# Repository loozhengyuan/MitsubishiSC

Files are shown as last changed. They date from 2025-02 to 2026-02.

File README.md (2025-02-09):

# MitsubishiSC



Smart controller for Mitsubishi Electric HVAC systems.

## Usage

The [`platformio.ini`](./platformio.ini) defines the list of build environments. Each board configuration comes in `debug` and `release` builds.

### Build

To compile the firmware, use the `pio run` command with the designated build environment.

```shell
pio run --environment mitsubishisc_v1_release
```

### Flash

To flash the build artifact to the board, connect the board and run the `pio run` command with the `upload` target.

```shell
pio run --target upload --environment mitsubishisc_v1_release
```

## Concepts

### Protocol

The CN105 connector exposes the UART interface via the RX and TX pins. As [discovered by Hadley Rich](https://nicegear.nz/blog/hacking-a-mitsubishi-heat-pump-air-conditioner/), this uses 5V TTL 2400 8-E-1.

Since the ESP32/STM32 runs on 3.3V while the UART runs on 5V, there is a need to use a logic level shifter. [BSS138](https://www.onsemi.com/pdf/datasheet/bss138-d.pdf) is a N-channel MOSFET with a low $V_{GS(th)}$, which makes it [more ideal than other NMOS components](https://electronics.stackexchange.com/questions/242424/what-can-i-replace-a-bss138-n-channel-mosfet-with).

For more information about the packets, refer to [mUART Protocol Reference](https://muart-group.github.io/developer/packet-reference).

## Hardware

### MCU

As part of the project goals, we want to build a device that leverages on the [Matter](https://csa-iot.org/all-solutions/matter/) standard for maximum compatibility and [Thread](https://www.threadgroup.org) for low-power, low-latency performance. The selected microcontroller should have the following features:

- Support for WiFi and Thread
- Support for Matter over WiFi/Thread

| Manufacturer | MPN | Type | Price |
| --- | --- | ---- | --- |
| Espressif Systems | [`ESP32-C6FH4`](https://www.espressif.com/sites/default/files/documentation/esp32-c6_datasheet_en.pdf) | SoC  | |
| Espressif Systems | [`ESP32-C6-MINI-1`](https://www.espressif.com/sites/default/files/documentation/esp32-c6-mini-1_mini-1u_datasheet_en.pdf) | SoC  | |
| STMicroelectronics | [`STM32WB55CGU6`](https://www.st.com/resource/en/datasheet/stm32wb55cg.pdf) | SoC  | [US$3.48](https://www.lcsc.com/product-detail/Microcontroller-Units-MCUs-MPUs-SOCs_STMicroelectronics-STM32WB55CGU6_C404023.html) |
| STMicroelectronics | [`STM32WB5MMG`](https://www.st.com/resource/en/datasheet/stm32wb5mmg.pdf) | SoC  | |
| Nordic Semiconductor | [`NRF52840-QIAA-R`](https://docs-be.nordicsemi.com/bundle/ps_nrf52840/attach/nRF52840_PS_v1.9.pdf) | SoC  | [US$3.41](https://www.lcsc.com/product-detail/RF-Transceiver-ICs_Nordic-Semicon-NRF52840-QIAA-R_C190794.html) |

_NOTE: The SKUs from [LCSC](https://www.lcsc.com) Popular Products are preferred to ensure good price and supply._

### Connector

The Mitsubishi Electric air conditioner has a `CN105` port that appears to be a [JST PA](https://www.jst.com/products/appliance-connectors/pa-family/) connector. To fit this, we should use `PAP-05V-S` housing with `SPHD-001T-P0.5`/`SPHD-002T-P0.5` contacts.

DigiKey stocks the `APALPA22K305`/`APAPA22K305` pre-crimped cables in 22 AWG, 12" cables.

According to the [LCSC](https://www.lcsc.com) team, the HCTL [`HC-PA-5Y`](https://www.lcsc.com/product-detail/Rectangular-Connectors-Housings_HCTL_C2962360.html) and [`HC-PA-T`](https://www.lcsc.com/product-detail/Line-Pressing-Terminals_HCTL-HC-PA-T_C2962368.html) are equivalent replacements for this part.

### Power Supply

The STM32/ESP32 runs on 3.3V but the `CN105` connector only exposes 12V and 5V power rails.

To power the MCU, we use a low-dropout linear regulator to regulate 5V to 3.3V. `MCP1700` is chosen for its low quiescent current ($I_Q$) but any modern LDO should work.

## License

[MIT](https://choosealicense.com/licenses/mit/)

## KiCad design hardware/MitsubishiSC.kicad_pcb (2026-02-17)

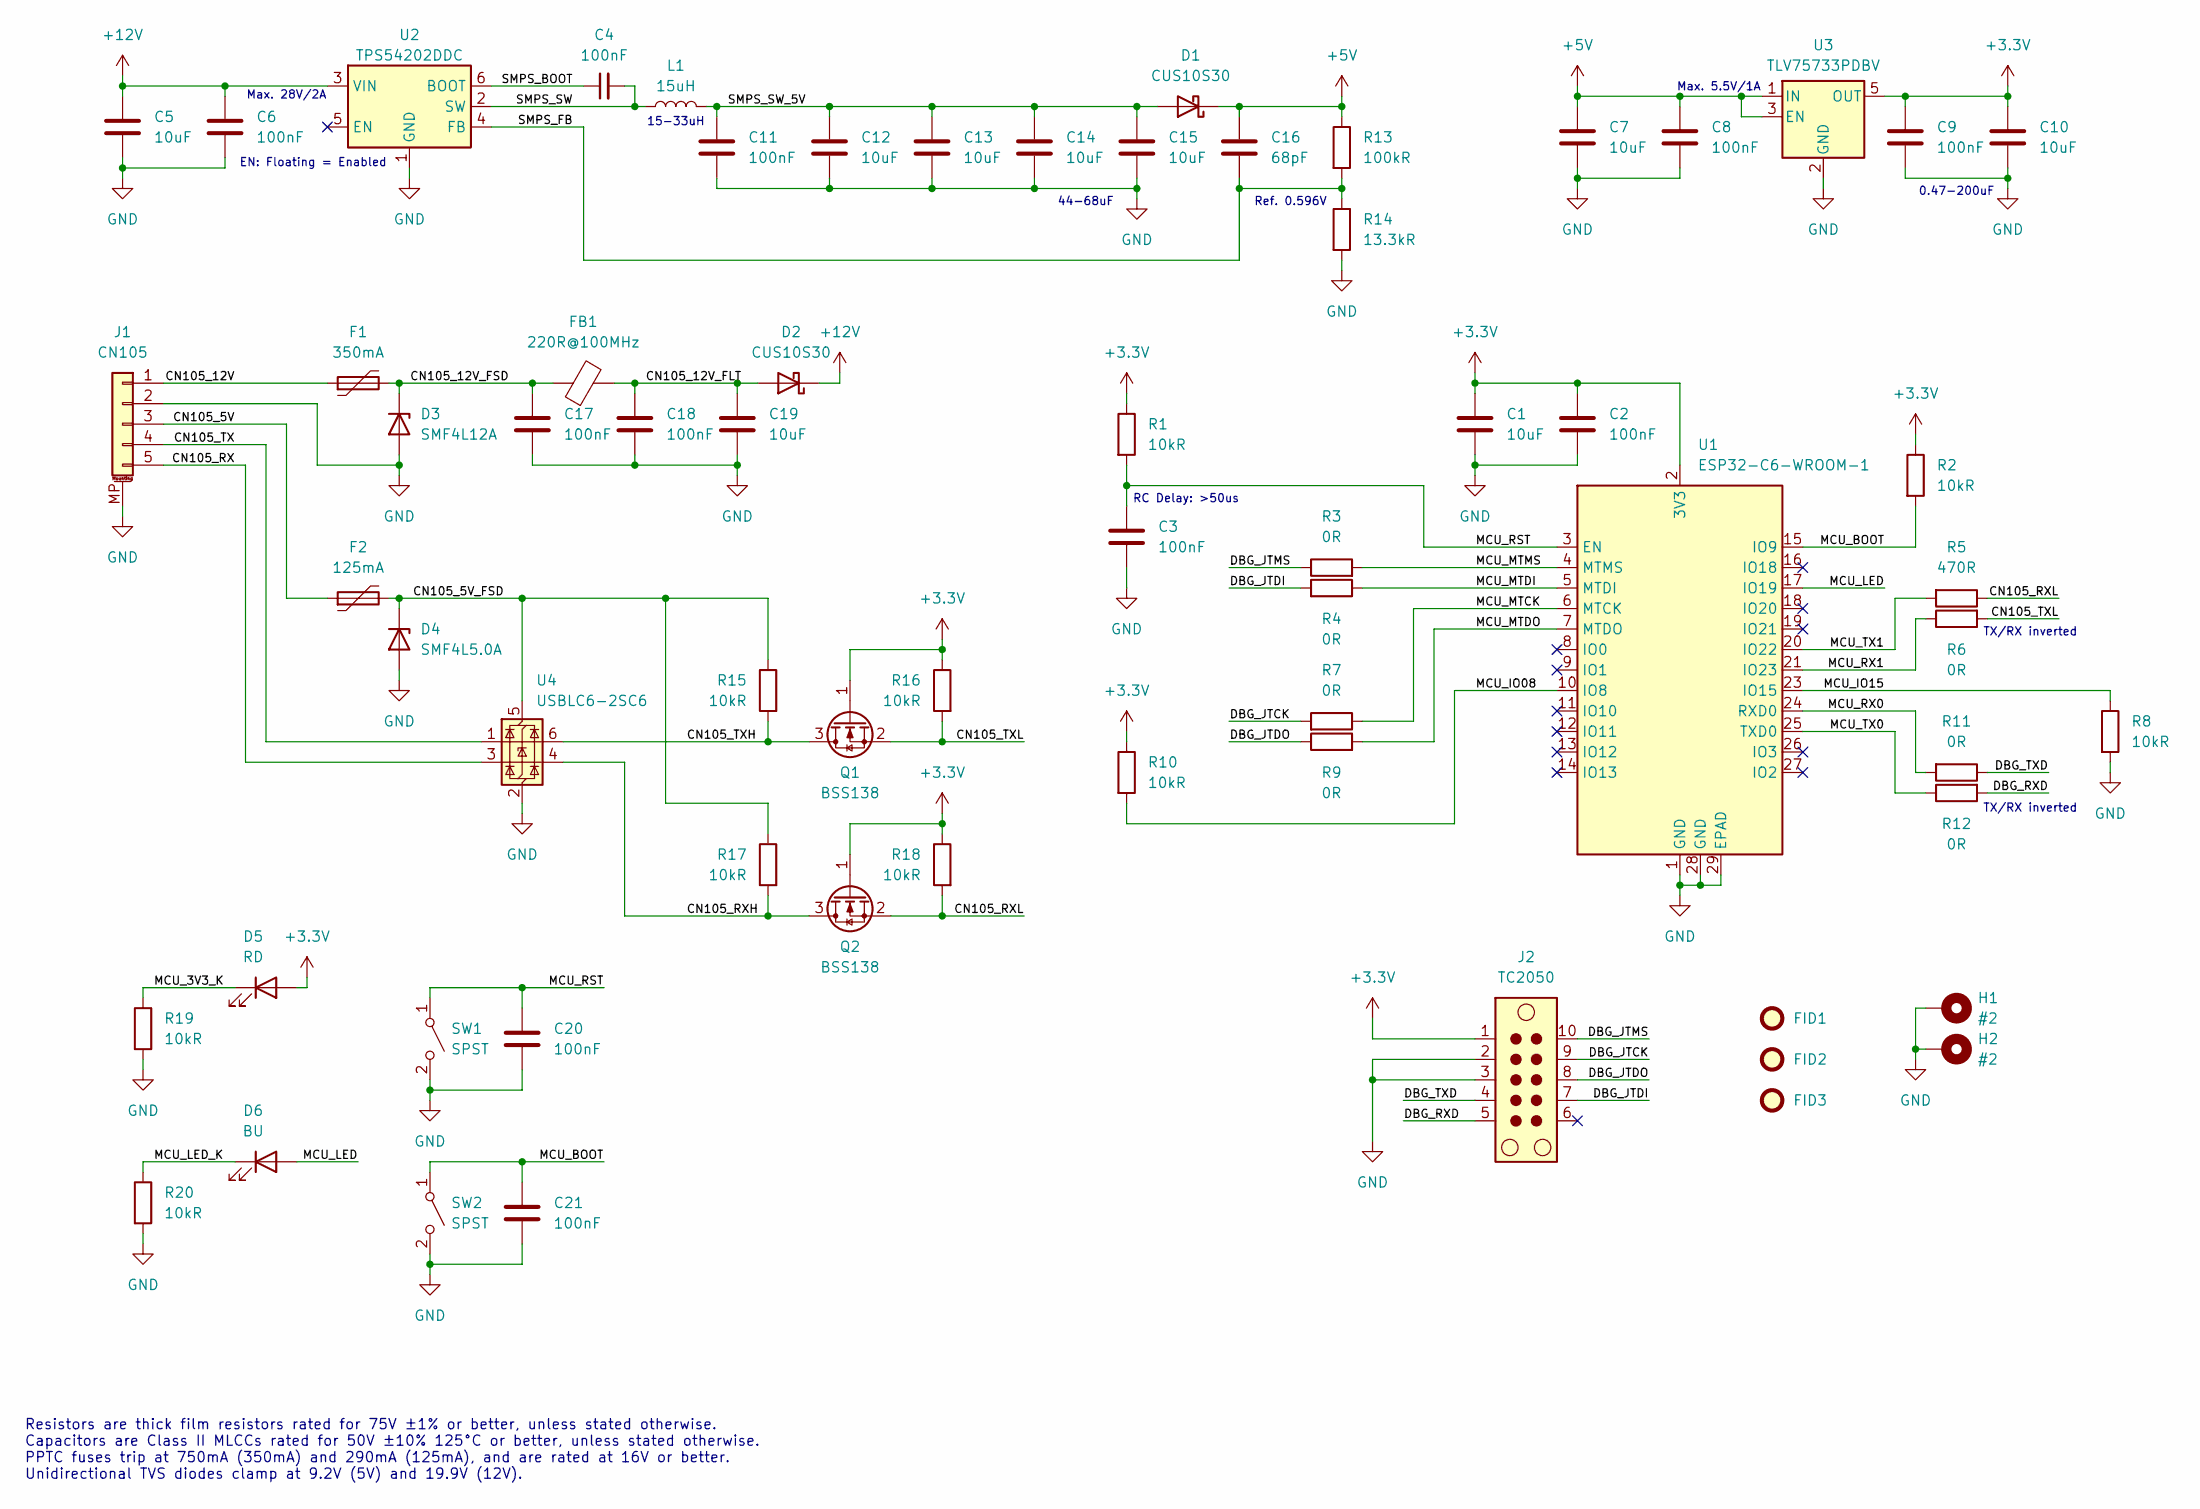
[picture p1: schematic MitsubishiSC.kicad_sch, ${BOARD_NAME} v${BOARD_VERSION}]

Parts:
C1, C5, C7, C10, C12, C13, C14, C15, C19: 10uF; C_1206_3216Metric; Manufacturer Part Number CL31B106KBHNNNE
C2, C3, C4, C6, C8, C9, C11, C17, C18, C20, C21: 100nF; C_0603_1608Metric; Manufacturer Part Number CL10B104KC8NNNC
C16: 68pF; C_0603_1608Metric; Manufacturer Part Number CL10C680JB8NNNC
D1, D2: CUS10S30; D_SOD-323; Manufacturer Part Number CUS10S30,H3F
D3: SMF4L12A; D_SOD-123F; Manufacturer Part Number SMF4L12A
D4: SMF4L5.0A; D_SOD-123F; Manufacturer Part Number SMF4L5.0A
D5: RD; LED_0805_2012Metric; Manufacturer Part Number XL-2012SURC
D6: BU; LED_0805_2012Metric; Manufacturer Part Number XL-2012UBC
F1: 350mA; Fuse_1206_3216Metric; Manufacturer Part Number 1206L035/16YR
F2: 125mA; Fuse_1206_3216Metric; Manufacturer Part Number 1206L012WR
FB1: 220R@100MHz; L_0805_2012Metric; Manufacturer Part Number BLM21PG221SN1D
FID1, FID2, FID3: Fiducial; Fiducial_1mm_Mask2mm
H1, H2: #2; MountingHole_2.5mm_Pad_Via; Manufacturer Part Number 1553WTS100
J1: CN105; JST_PA_SM05B-PASS_1x05_P2.00mm_Horizontal; Manufacturer Part Number SM05B-PASS-TBT(LF)(SN)
J2: TC2050; Tag-Connect_TC2050-IDC-NL_2x05_P1.27mm_Vertical
L1: 15uH; L_TDK_VLS6045EX_VLS6045AF; Manufacturer Part Number VLS6045EX-150M
Q1, Q2: BSS138; SOT-23; Manufacturer Part Number BSS138
R1, R2, R8, R10, R15, R16, R17, R18, R19, R20: 10kR; R_0603_1608Metric; Manufacturer Part Number RC0603FR-0710KL
R3, R4, R6, R7, R9, R11, R12: 0R; R_0603_1608Metric; Manufacturer Part Number RC0603FR-070RL
R5: 470R; R_0603_1608Metric; Manufacturer Part Number RC0603FR-07470RL
R13: 100kR; R_0603_1608Metric; Manufacturer Part Number RC0603FR-07100KL
R14: 13.3kR; R_0603_1608Metric; Manufacturer Part Number RC0603FR-0713K3L
SW1, SW2: SPST; SW_SPST_PTS810; Manufacturer Part Number GT-TC048D-H025-L1
U1: ESP32-C6-WROOM-1; Manufacturer Part Number ESP32-C6-WROOM-1-N8
U2: TPS54202DDC; SOT-23-6; Manufacturer Part Number TPS54202DDCR
U3: TLV75733PDBV; SOT-23-5; Manufacturer Part Number TLV75733PDBVR
U4: USBLC6-2SC6; SOT-23-6; Manufacturer Part Number USBLC6-2SC6

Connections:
+3.3V: C1.1, C2.1, C9.1, C10.1, D5.2 (A), J2.1, Q1.1 (G), Q2.1 (G), R1.1, R2.1, R10.1, R16.1, R18.1, U1.2 (3V3), U3.5 (OUT)
+5V: C7.1, C8.1, C16.1, D1.1 (K), R13.1, U3.1 (IN), U3.3 (EN)
+12V: C5.1, C6.1, D2.1 (K), U2.3 (VIN)
/CN105_5V: F2.1, J1.3 (5V)
/CN105_5V_FSD: D4.1 (K), F2.2, R15.1, R17.1, U4.5 (VBUS)
/CN105_12V: F1.1, J1.1 (12V)
/CN105_12V_FLT: C18.1, C19.1, D2.2 (A), FB1.2
/CN105_12V_FSD: C17.1, D3.1 (K), F1.2, FB1.1
/CN105_RX: J1.5 (TX), U4.3 (I/O2)
/CN105_RXH: Q2.3 (D), R17.2, U4.4 (I/O2)
/CN105_RXL: Q2.2 (S), R5.1, R18.2
/CN105_TX: J1.4 (RX), U4.1 (I/O1)
/CN105_TXH: Q1.3 (D), R15.2, U4.6 (I/O1)
/CN105_TXL: Q1.2 (S), R6.2, R16.2
/DBG_JTCK: J2.9, R7.2
/DBG_JTDI: J2.7, R4.2
/DBG_JTDO: J2.8, R9.1
/DBG_JTMS: J2.10, R3.1
/DBG_RXD: J2.5, R12.2
/DBG_TXD: J2.4, R11.1
/MCU_3V3_K: D5.1 (K), R19.1
/MCU_BOOT: C21.1, R2.2, SW2.1 (A), U1.15 (IO9)
/MCU_IO08: R10.2, U1.10 (IO8)
/MCU_IO15: R8.1, U1.23 (IO15)
/MCU_LED: D6.2 (A), U1.17 (IO19)
/MCU_LED_K: D6.1 (K), R20.1
/MCU_MTCK: R7.1, U1.6 (MTCK)
/MCU_MTDI: R4.1, U1.5 (MTDI)
/MCU_MTDO: R9.2, U1.7 (MTDO)
/MCU_MTMS: R3.2, U1.4 (MTMS)
/MCU_RST: C3.1, C20.1, R1.2, SW1.1 (A), U1.3 (EN)
/MCU_RX0: R11.2, U1.24 (RXD0)
/MCU_RX1: R6.1, U1.21 (IO23)
/MCU_TX0: R12.1, U1.25 (TXD0)
/MCU_TX1: R5.2, U1.20 (IO22)
/SMPS_BOOT: C4.1, U2.6 (BOOT)
/SMPS_FB: C16.2, R13.2, R14.1, U2.4 (FB)
/SMPS_SW: C4.2, L1.1, U2.2 (SW)
/SMPS_SW_5V: C11.1, C12.1, C13.1, C14.1, C15.1, D1.2 (A), L1.2
GND: C1.2, C2.2, C3.2, C5.2, C6.2, C7.2, C8.2, C9.2, C10.2, C11.2, C12.2, C13.2, C14.2, C15.2, C17.2, C18.2, C19.2, C20.2, C21.2, D3.2 (A), D4.2 (A), H1.1, H2.1, J1.2 (GND), J1.MP (MountPin), J2.2, J2.3, R8.2, R14.2, R19.2, R20.2, SW1.2 (B), SW2.2 (B), U1.1 (GND), U1.28 (GND), U1.29 (EPAD), U2.1 (GND), U3.2 (GND), U4.2 (GND)

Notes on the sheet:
TX/RX inverted
15-33uH
Ref. 0.596V
EN: Floating = Enabled
Max. 28V/2A
Max. 5.5V/1A
0.47-200uF
44-68uF
Resistors are thick film resistors rated for 75V ±1% or better, unless stated otherwise. Capacitors are Class II MLCCs rated for 50V ±10% 125°C or better, unless stated otherwise. PPTC fuses trip at 750mA (350mA) and 290mA (125mA), and are rated at 16V or better. Unidirectional TVS diodes clamp at 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
RC Delay: >50us

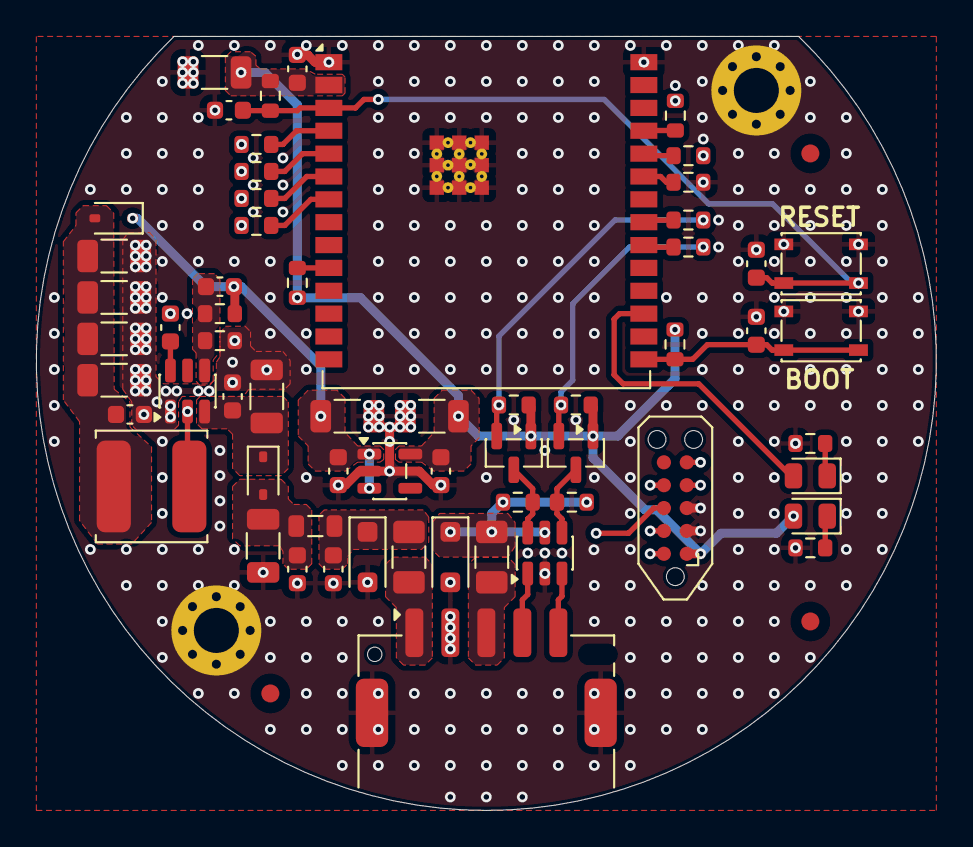
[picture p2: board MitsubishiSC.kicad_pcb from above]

Board: 6 copper layers, 50.0 x 43.0 mm, 66 parts (0 on the bottom side), 40 nets.

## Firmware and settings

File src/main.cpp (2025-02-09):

#include <Arduino.h>
#include <WiFi.h>

#include <ArduinoJson.h>
#include <HeatPump.h>
#include <PubSubClient.h>

#include "AirConditioningController.hpp"
#include "HomeKitAirConditioner.hpp"

#ifndef WIFI_SSID
#define WIFI_SSID ""
#endif
#ifndef WIFI_PASS
#define WIFI_PASS ""
#endif

#ifdef MITSUBISHISC_V1
#define USER_LED 10
#else
#define USER_LED LED_BUILTIN
#endif

#define USER_BTN 9

#define CONN_RXD 0
#define CONN_TXD 1

char deviceId[30];

WiFiClient wifi;
HeatPump hp;
AirConditioningController
    ctrl(deviceId, &wifi, &hp, CONN_RXD, CONN_TXD, USER_LED, USER_BTN);

void setup() {
  Serial.begin(115200);

  delay(1000);  // Give time for serial monitor to initialize
  Serial.printf("Reset reason: %d\n", esp_reset_reason());

  pinMode(USER_LED, OUTPUT);

  // Derive device identifier
  snprintf(deviceId, sizeof(deviceId), "mitsubishisc-%016llx",
           ESP.getEfuseMac());
  Serial.printf("Device ID: %s\n", deviceId);

  // Set up WiFi
  Serial.println("Setting up WiFi");
  WiFi.hostname(deviceId);
  WiFi.mode(WIFI_STA);
  WiFi.setTxPower(WIFI_POWER_2dBm);  // NOTE: No need to go full power
  WiFi.setAutoReconnect(true);
  WiFi.begin(WIFI_SSID, WIFI_PASS);
  while (WiFi.status() != WL_CONNECTED) {
    Serial.printf("Connecting to WiFi: %d\n", WiFi.status());
    delay(1000);
    digitalWrite(USER_LED, HIGH);
    delay(500);
    digitalWrite(USER_LED, LOW);
  }

  // Set up controller
  ctrl.setup();
  Serial.println("Set up completed!");
}

void loop() {
  ctrl.loop();
}

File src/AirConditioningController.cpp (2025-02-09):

#include <ArduinoJson.h>

#include "AirConditioningController.hpp"

AirConditioningController::AirConditioningController(char* deviceId,
                                                     WiFiClient* wifi,
                                                     HeatPump* hp,
                                                     uint8_t rxPin,
                                                     uint8_t txPin,
                                                     uint8_t userLedPin,
                                                     uint8_t userBtnPin) {
  this->deviceId = deviceId;

  this->rxPin = rxPin;
  this->txPin = txPin;
  this->userLedPin = userLedPin;
  this->userBtnPin = userBtnPin;

  Serial.println("Setting up stuff");
  this->mqtt = new MQTTClient(deviceId);
  this->mqtt->setWiFiClient(*wifi);
  this->hp = hp;

  this->pubSubTopicSettings = "ac/settings";
  this->pubSubTopicStatus = "ac/status";
  this->pubSubTopicTimers = "ac/timers";
  this->pubSubTopicDebug = "ac/debug";
}

AirConditioningController::~AirConditioningController() {
  if (mqtt != nullptr) {
    delete mqtt;
  }
  if (hk != nullptr) {
    delete hk;
  }
}

void AirConditioningController::setup() {
  Serial.println("Initializing Air Conditioning Controller");

  hp->setFastSync(true);
  // NOTE: Configs set by IR remote should still remain
  hp->enableExternalUpdate();

  // NOTE: `setPacketCallback` should be called before `connect`
  // so the initial packets will also be logged.
  Serial.println("Setting up callbacks");
  hp->setSettingsChangedCallback(
      std::bind(&AirConditioningController::handleSettingsChanged, this));
  hp->setStatusChangedCallback(
      std::bind(&AirConditioningController::handleStatusChanged, this,
                std::placeholders::_1));
  hp->setPacketCallback(std::bind(
      &AirConditioningController::handlePacketReceived, this,
      std::placeholders::_1, std::placeholders::_2, std::placeholders::_3));

  Serial.println("Connecting to UART1");
  Serial1.begin(2400, SERIAL_8E1, rxPin, txPin);
  hp->connect(&Serial1);

  // Set up HomeKit device
  homeSpan.setLogLevel(2);
  homeSpan.setControlPin(userBtnPin);
  homeSpan.setStatusPin(userLedPin);
  homeSpan.setStatusAutoOff(10);  // 10s
  homeSpan.begin(Category::AirConditioners, "Mitsubishi Electric",
                 deviceId);  // TODO: Must be unique?

  new SpanAccessory();
  new Service::AccessoryInformation();
  new Characteristic::Identify();
  new Characteristic::Name("Air Conditioner");
  new Characteristic::Manufacturer("Mitsubishi Electric");
  // new Characteristic::Model("");
  new Characteristic::FirmwareRevision("0.1.0");

  // FIXME: Why this cannot be called in the constructor?
  this->hk = new HomeKitAirConditioner();

  hk->setStateUpdateCallback(
      std::bind(&AirConditioningController::handleHomeKitPowerUpdated, this,
                std::placeholders::_1));
  hk->setModeUpdateCallback(
      std::bind(&AirConditioningController::handleHomeKitTargetStateUpdated,
                this, std::placeholders::_1));
  hk->setOscillationUpdateCallback(
      std::bind(&AirConditioningController::handleHomeKitSwingModeUpdated, this,
                std::placeholders::_1));
  hk->setFanSpeedUpdateCallback(
      std::bind(&AirConditioningController::handleHomeKitRotationSpeedUpdated,
                this, std::placeholders::_1));
  hk->setTempCoolUpdateCallback(
      std::bind(&AirConditioningController::handleHomeKitTargetTempCoolUpdated,
                this, std::placeholders::_1));

  Serial.println("Completed setup for Air Conditioning Controller");
}

void AirConditioningController::loop() {
  mqtt->tryConnect();

#ifdef DEBUG
  uint32_t currentTime = millis();
  if (currentTime - lastDebugPublished > 10000) {
    float chipTemp = temperatureRead();
    char message[40];
    snprintf(message, sizeof(message), "Retrieved ESP32 temperature: %.1f°C",
             chipTemp);
    Serial.println(message);
    publish(pubSubTopicDebug, message);
    lastDebugPublished = currentTime;
  }
#endif

  hp->sync();
  homeSpan.poll();
}

void AirConditioningController::publish(const char* topic,
                                        const char* payload) {
  if (mqtt->isConnected() && !mqtt->publish(topic, payload)) {
    char errorMessage[512];
    snprintf(errorMessage, sizeof(errorMessage),
             "failed to publish to topic: %s: %s", topic, payload);
    Serial.println(errorMessage);
    mqtt->publish(pubSubTopicDebug, errorMessage);
  }
}

void AirConditioningController::publishSettings(heatpumpSettings current) {
  JsonDocument payload;
  payload["power"] = current.power;
  payload["mode"] = current.mode;
  payload["temperature"] = current.temperature;
  payload["fan"] = current.fan;
  payload["vane"] = current.vane;
  payload["wideVane"] = current.wideVane;

  char buffer[512];
  serializeJson(payload, buffer);
  publish(pubSubTopicSettings, buffer);
}

void AirConditioningController::publishStatus(heatpumpStatus current) {
  JsonDocument payload;
  payload["roomTemperature"] = current.roomTemperature;
  payload["operating"] = current.operating;
  payload["compressorFrequency"] = current.compressorFrequency;

  char buffer[512];
  serializeJson(payload, buffer);
  publish(pubSubTopicStatus, buffer);
}

void AirConditioningController::publishTimers(heatpumpTimers current) {
  JsonDocument payload;
  payload["mode"] = current.mode;
  payload["onMins"] = current.onMinutesSet;
  payload["onRemainMins"] = current.onMinutesRemaining;
  payload["offMins"] = current.offMinutesSet;
  payload["offRemainMins"] = current.offMinutesRemaining;

  char buffer[512];
  serializeJson(payload, buffer);
  publish(pubSubTopicTimers, buffer);
}

void AirConditioningController::publishPacket(byte* packet,
                                              unsigned int length,
                                              char* direction) {
  String message;
  for (int idx = 0; idx < length; idx++) {
    if (packet[idx] < 16) {
      message += "0";  // pad single hex digits with a 0
    }
    message += String(packet[idx], HEX) + " ";
  }

  JsonDocument payload;
  payload[direction] = message;

  char buffer[512];
  serializeJson(payload, buffer);
  publish(pubSubTopicDebug, buffer);
}

void AirConditioningController::handleSettingsChanged() {
  heatpumpSettings current = hp->getSettings();
  publishSettings(current);

  handleHeatPumpPowerUpdated(current.power);
  handleHeatPumpModeUpdated(current.mode);
  handleHeatPumpVaneUpdated(current.vane);
  handleHeatPumpFanUpdated(current.fan);
  handleHeatPumpTempUpdated(current.temperature);
}
void AirConditioningController::handleStatusChanged(heatpumpStatus status) {
  publishStatus(status);
  publishTimers(status.timers);

  handleHeatPumpRoomTemperatureUpdated(status.roomTemperature);
}
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

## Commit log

2025-08-24 chore: update settings.yml (#7)
    This commit re-enables the GitHub issues feature.
    Trace-Id: 23fadd9f68ca3d3bfc1a37cbc85930d7
2025-08-25 chore: update github config (#8)
    This commit removes `has_issues` because it was recently re-enabled.
    Trace-Id: 3a8621aa3f26bfdbd8048a3661baacfb
2025-09-17 feat: add pcb prototype
    This commit adds the initial implementation the PCB.
    [MitsubishiSC.kicad_pcb, MitsubishiSC.kicad_sch]
2025-09-17 feat: upgrade to KiCad v9 (#14)
    This commit upgrades the KiCad files to `9.0.4`.
    [MitsubishiSC.kicad_pcb, MitsubishiSC.kicad_sch]
2025-09-18 feat(hw): switch to export script (#15)
    This commit switches to use shell scripts for KiCad exports.
    Using shell scripts make it easier to test locally and reuse across
    various projects.
2025-09-18 feat(hw): enable 3D model/render exports (#16)
    This commit adds support for exporting 3D renders and models for PCB.
2025-09-18 fix(hw): swap C6/C17 cap placement (#17)
    This commit fixes an issue with the SMPS output cap placement where the
    100nF capacitor should have been placed closest to the pins but is not
    the case.
    [MitsubishiSC.kicad_pcb]
2025-09-18 feat(hw): reduce LED brightness (#18)
    This commit reduces the brightness of the indicator LED by increasing
    the resistor value of R8 from 1kR to 10kR. Although the resistor value
    is on the higher side, this is generally fine because the use of LED is
    not user-facing.
    [MitsubishiSC.kicad_pcb, MitsubishiSC.kicad_sch]
2025-09-19 fix(hw): incorrect PPTC footprint (#19)
    This commit fixes the incorrect PPTC footprint size.
    The existing schematic specifies the Bourns MF-MSMF030-2 part which
    should be using the `Fuse_1812_4532Metric` footprint but was instead
    assigned the `Fuse_1206_3216Metric` footprint. As a result, the
    component CANNOT be placed on the circuit board.
    To rectify this, we changed the component to use the Littelfuse
    1206L035/16 part instead, which is almost similar to the specifications
    of the original part.
    Importantly, a deliberate decision was made to swap component instead of
    correcting the footprint in order to avoid the significant change to the
    board layout required to accommodate the correct b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
    [MitsubishiSC.kicad_pcb, MitsubishiSC.kicad_sch]
2025-09-19 chore: bump version v0.2.0
    [MitsubishiSC.kicad_pcb]
2025-09-20 chore(deps): bump hardware/lib from `199c1e1` to `e7fd264` (#20)
    Bumps [hardware/lib](https://github.com/loozhengyuan/kicad) from `199c1e1` to `e7fd264`.
    - [Commits](https://github.com/loozhengyuan/kicad/compare/199c1e1a25dc3f4a231f425dc5fd3ef8ca8db975...e7fd264120bbb1a4f89bc8e4ca3f54ad22f7fd1c)
    ---
    updated-dependencies:
    - dependency-name: hardware/lib
    dependency-version: e7fd264120bbb1a4f89bc8e4ca3f54ad22f7fd1c
    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
2025-09-25 ci: pin actions by commit hash (#23)
    This commit updates the various actions to pin by hash instead of tag.
    Pinning by hash is widely considered to be best practice. Considering
    that Dependabot now has the ability to bump actions by hash[1], it makes
    sense to switch to pinning by hash.
    [1]: https://github.com/dependabot/dependabot-core/issues/4691
    Idempotency-Key: 2c8d6556e882ca6fa8c306df9653d268
2025-09-27 chore(deps): bump hardware/lib from `e7fd264` to `23258cb` (#24)
    Bumps [hardware/lib](https://github.com/loozhengyuan/kicad) from `e7fd264` to `23258cb`.
    - [Commits](https://github.com/loozhengyuan/kicad/compare/e7fd264120bbb1a4f89bc8e4ca3f54ad22f7fd1c...23258cb61563da85fa9d046a8a65338788b5317a)
    dependency-version: 23258cb61563da85fa9d046a8a65338788b5317a
    dependency-type: direct:production
    ...
    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
2025-10-18 chore(deps): bump hardware/lib from `23258cb` to `4d18a40` (#26)
    Bumps [hardware/lib](https://github.com/loozhengyuan/kicad) from `23258cb` to `4d18a40`.
    - [Commits](https://github.com/loozhengyuan/kicad/compare/23258cb61563da85fa9d046a8a65338788b5317a...4d18a40f2ec891081f94f9c6d18aeea6f3f264a1)
    dependency-version: 4d18a40f2ec891081f94f9c6d18aeea6f3f264a1
    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
2025-11-22 chore(deps): bump hardware/lib from `4d18a40` to `52a9a50` (#29)
    Bumps [hardware/lib](https://github.com/loozhengyuan/kicad) from `4d18a40` to `52a9a50`.
    - [Commits](https://github.com/loozhengyuan/kicad/compare/4d18a40f2ec891081f94f9c6d18aeea6f3f264a1...52a9a50c2a1da3880ab78c090232d2913ed1f7e4)
    dependency-version: 52a9a50c2a1da3880ab78c090232d2913ed1f7e4
    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
2025-12-06 chore(deps): bump hardware/lib from `52a9a50` to `768aa73` (#32)
    Bumps [hardware/lib](https://github.com/loozhengyuan/kicad) from `52a9a50` to `768aa73`.
    - [Commits](https://github.com/loozhengyuan/kicad/compare/52a9a50c2a1da3880ab78c090232d2913ed1f7e4...768aa733a1ab6b95ad2dd7de75842aa46bf29dfb)
    dependency-version: 768aa733a1ab6b95ad2dd7de75842aa46bf29dfb
    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
2025-12-22 chore(deps): bump hardware/lib from `768aa73` to `c08543f` (#35)
    Bumps [hardware/lib](https://github.com/loozhengyuan/kicad) from `768aa73` to `c08543f`.
    - [Commits](https://github.com/loozhengyuan/kicad/compare/768aa733a1ab6b95ad2dd7de75842aa46bf29dfb...c08543ffaef004d701582646cdbe2edbb014a9bf)
    dependency-version: c08543ffaef004d701582646cdbe2edbb014a9bf
    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
2026-01-03 chore(deps): bump hardware/lib from `c08543f` to `dacaa1f` (#36)
    Bumps [hardware/lib](https://github.com/loozhengyuan/kicad) from `c08543f` to `dacaa1f`.
    - [Commits](https://github.com/loozhengyuan/kicad/compare/c08543ffaef004d701582646cdbe2edbb014a9bf...dacaa1fac1e62226a4627610998bff69c53f02f0)
    dependency-version: dacaa1fac1e62226a4627610998bff69c53f02f0
    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
2026-01-10 feat(pcb): revamp design and layout
    This commit makes significant changes to the PCB, primarily changing the
    MCU from ESP32-C3 to ESP32-C6 to accommodate Matter-over-Thread.
    [MitsubishiSC.kicad_pcb, MitsubishiSC.kicad_sch]
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2026-01-17 chore(deps): bump hardware/lib from `dacaa1f` to `3c105d8` (#39)
    Bumps [hardware/lib](https://github.com/loozhengyuan/kicad) from `dacaa1f` to `3c105d8`.
    - [Commits](https://github.com/loozhengyuan/kicad/compare/dacaa1fac1e62226a4627610998bff69c53f02f0...3c105d891bb64ac8d859a714ecf152926401822e)
    dependency-version: 3c105d891bb64ac8d859a714ecf152926401822e
    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
2026-02-17 feat: redesign PCB layout (#41)
    [MitsubishiSC.kicad_pcb, MitsubishiSC.kicad_sch]
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2026-10-25 feat: migrate from HomeKit to Matter over Thread (#62)
    Replace the HomeKit implementation (HomeSpan on Arduino via PlatformIO)
    with a Matter-over-Thread implementation built on ESP-IDF, using ESP
    Matter through the Arduino ESP32 Matter library as an IDF component.
    Matter and Thread have been the project's goals from the start: Matter
    for compatibility across smart home ecosystems, Thread for low-power,
    low-latency networking. The prebuilt Arduino core only supports Matter
    over WiFi, so building on ESP-IDF directly is what enables Thread on
    the ESP32-C6.
    The air conditioner is now exposed as a cooling-only Matter thermostat
    (power, cooling setpoint, room temperature). Network credentials ar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
2026-10-26 feat: upgrade to ESP-IDF v5.5.5 (#63)
    Upgrade ESP-IDF from v5.5.1 to v5.5.5 along with the components that
    are built against it:
    - espressif/arduino-esp32: 3.3.5 -> 3.3.12
    - espressif/esp_matter: 1.4.1 -> 1.5.1
    arduino-esp32 3.3.12 ships prebuilt libs built from ESP-IDF v5.5.5
    (b774170f) and esp_matter 1.5.1, per versions.txt in its
    esp32-arduino-libs archive. esp_matter 1.6.x is not compatible with
    arduino-esp32 3.x (espressif/arduino-esp32#12851), and the previous
    esp_matter 1.4.1 pin has been yanked from the component registry.
    esp_matter 1.5 fails to compile the ClosureControl cluster with GCC 14
    and C++20. Force-include arduino-esp32's matter_closure_patch.h into
    esp_matter, mirrorin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
2026-10-26 chore: drop kicad-cli --rotate workaround (#64)
    KiCad 9.0.8 fixed negative value parsing in `--rotate`, so the
    leading-space workaround is no longer needed.
    Link: https://gitlab.com/kicad/code/kicad/-/issues/2019
2026-10-26 chore: remove Matter thermostat FIXME (#65)
    Fixed upstream in Arduino Core 3.3.12 (espressif/arduino-esp32#12382).
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2026-11-09 chore: remove lingering KiCad 9 references (#69)
    Fetch the KiCad 3D models at tag 10.0.7 in CI instead of 9.0.6, so
    they match the kicad/kicad:10.0.7 image used to run the exports.
    Point 9 footprints in the PCB at KICAD10_3DMODEL_DIR instead of
    KICAD9_3DMODEL_DIR. The other footprints were already migrated, and
    the old variable is not defined in a KiCad 10 setup, so these models
    were likely missing from the renders and STEP/VRML exports.
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
